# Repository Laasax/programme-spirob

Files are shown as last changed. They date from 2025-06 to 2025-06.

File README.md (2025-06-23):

> Open this page at [https://laasax.github.io/programme-spirob/](https://laasax.github.io/programme-spirob/)

# Spirob - TUS - Tentacule Ultra Sophistiqué
## 1.1. Descriptif du projet
Le projet est à l’initiative d’un professeur de technologie du collège Les Hautes Ourmes de Rennes.
Il s'agit de la conception et du développement d'un tentacule biomimétique, s'inspirant des propriétés d'un tentacule de poulpe ou d'une trompe d'éléphant. Cette approche repose sur le mimétisme, une stratégie qui consiste à s'inspirer du fonctionnement des êtres vivants pour concevoir une nouvelle solution de bras robotique.
Le tentacule Spirobs sera conçu de manière à reproduire des mouvements fluides et adaptatifs similaires à ceux observés dans la nature. Ce projet implique plusieurs disciplines techniques, notamment la modélisation 3D, l'électronique, la programmation embarquée et un contrôle à distance via Bluetooth.

## 1.2. Objectifs
L'objectif principal du projet est de fournir un outil pédagogique permettant aux collégiens de découvrir les principes fondamentaux de la programmation et de la robotique dans le cadre de la matière Technologie.
Impression 3D : Mettre en place l’impression du tentacule et trouver le filament correspondent (pour correspondre à l’élasticité du bras)
Développement d'une librairie logicielle : Fournir des méthodes simples par le biais d’une librairie pour l’utiliser sur l’interface Makecode de Microsoft, afin qu’elle soit facilement utilisée par les collégiens.
Intégration d’un moyen communicant sans fil : Utilisation du module Bluetooth intégré de la carte MicroBit.

## 1.3. Composition des membres du projet
Pour réaliser ce projet, la composition de ce groupe sera composée de :
* Binta Ba
* Mouhsine Ben Chakrina
* Hugo Colombel
* Alexandre Bloino

# 2. Pré-requis

Installer les librairies suivantes:
* Radio

# 3. Pins utilisés

Voici l'ensemble des pins utilisés par rapport à la carte électronique conçu pour ce projet.

* P0	: Controle Moteur 1
* P1	: Feedback Moteur 1
* P2	: Feedback Moteur 2
* P3	: Mesure intensité Moteur 1
* P8	: Controle Moteur 2
* P10	: Mesure intensité Moteur 2

# 4. Description du dépot Github

Ce dépot Github comporte principalement la partie programmation sur Makecode de la tentacule.

## 4.1 Dossier Ressources

Ce dossier possède tous les plans et schémas pour réaliser le Spirob.
* Electronique:
Le schéma électronique est fait avec le logiciel Proteus, un gerber est fournie pour refaire des cartes.
* CAO 3D:
La réalisation 3D est faite avec le logiciel Solidworks, tous les fichiers STL sont fournies pour pouvoir les imprimer (boitier, tentacule...)

## 4.2 Dossier Images

Ce dossier permet de répertorier les captures d'écran / photo liés au projet, permettant de le contextualiser.

# 5. Fonctionnement du programme

## 5.1 Importer le programme 

### 5.1.1 Carte émettrice
Pour la carte émettrice, la librairie Radio doit être importée.
Dans ce programme, il faut prendre la fonction Radio Set Group, la mettre dans la boucle Setup, il faut ensuite, dans la boucle infini, envoyé l'orientation "roll" toutes les 50ms sur la communication radio.



### 5.1.2 Carte réceptrice
Pour la carte réceptrice, il faut importer le dépot Git depuis le bouton extension, puis coller le lien Git.

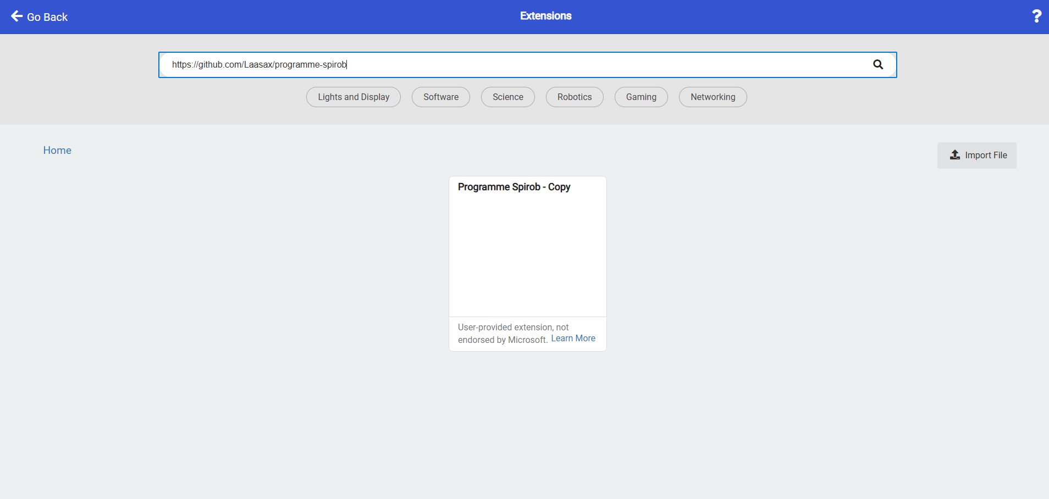
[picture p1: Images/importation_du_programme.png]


## 5.2 Fonctionnement
Afin de faire fonctionner le Spirob, il faut alimenter les 2 cartes MicroBit et alimenter la carte des servomoteurs.
Lorsque tout est alimenté, il suffit d'orienter de gauche à droite pour apprécier les mouvements de la tentacule.

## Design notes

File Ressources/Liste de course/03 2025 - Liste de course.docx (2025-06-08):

Gotronic :

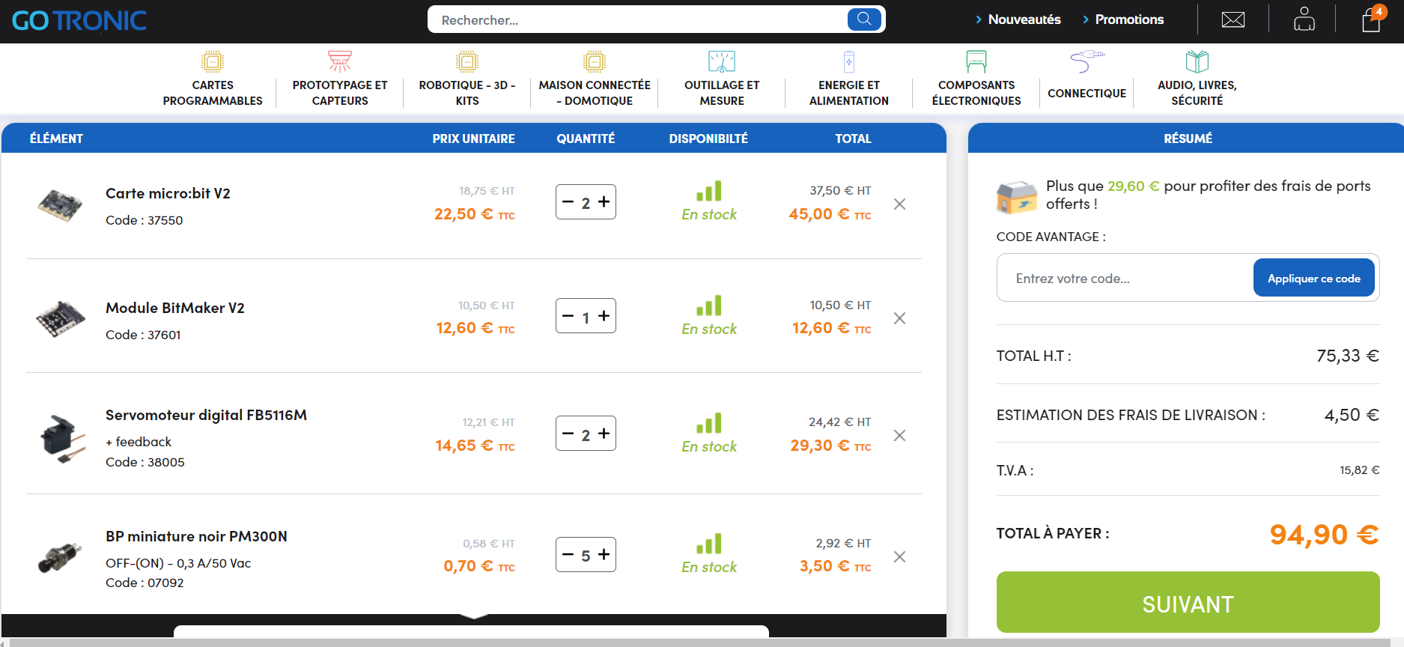
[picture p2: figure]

Mouser :

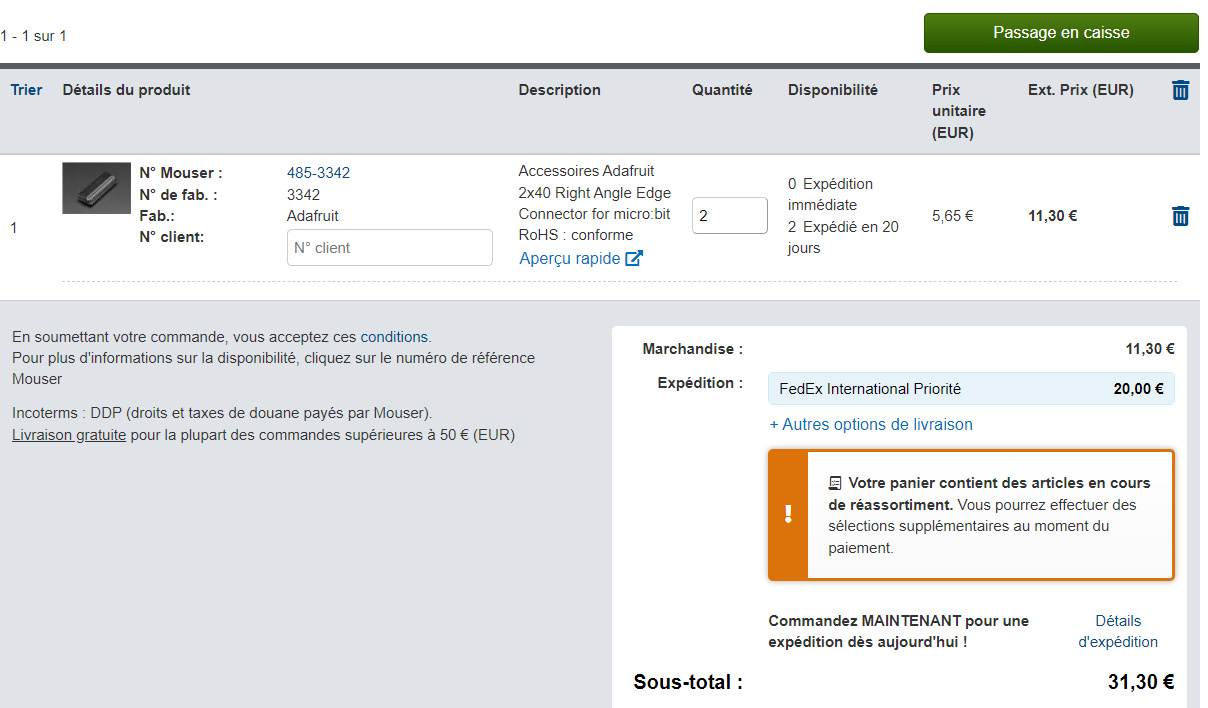
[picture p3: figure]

Atlantic Composant :

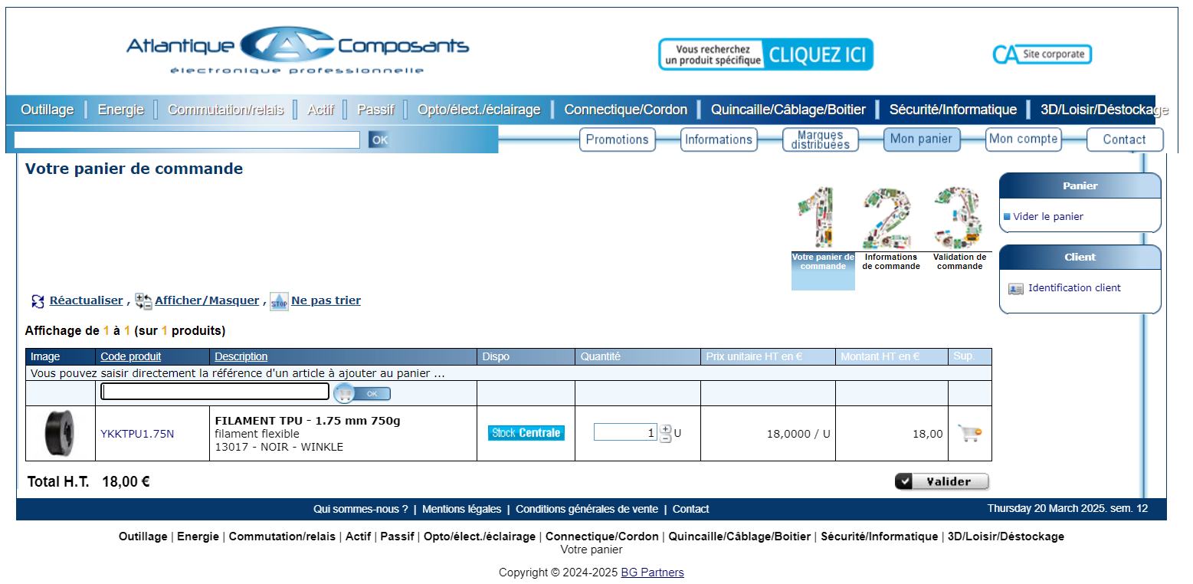
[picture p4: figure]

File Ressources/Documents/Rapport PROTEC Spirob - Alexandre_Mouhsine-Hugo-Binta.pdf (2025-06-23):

# Spirob – TUS – Tentacule Ultra Sophistiqué

BLOINO Alexandre
ESIR,
Université de Rennes
France
alexandre.bloino@etudia
nt.univ-rennes.fr

BA Mamadou Binta
ESIR,
Université de Rennes
France
mamadoubinta.ba@etudiant.univ-rennes.fr

COLOMBEL Hugo
ESIR,
Université de Rennes
France
hugo.colombel@etudiant
.univ-rennes1.fr

CHAKRINA Mouhsine
Ben
ESIR,
Université de Rennes
France
mouhsineben.chakrina@etudiant.u
niv-rennes.fr

Abstract

Projet de bras robotique biomimétique conçu pour l’enseignement de la technologie au collège. TUS s’inspire du mouvement des tentacules pour créer une interface programmable, contrôlée via une carte

MicroBit en Bluetooth. Ce rapport décrit la conception mécanique, les choix techniques, et l’implémentation logicielle avec l’objectif de créer un outil pédagogique accessible aux collégiens.

Index Terms – Biomimétisme ; Robotique pédagogique ; Impression 3D ; MicroBit ; Bluetooth ; MakeCode

I. INTRODUCTION

Le projet d’un bras robotique, reprenant la forme d’un tentacule, est un projet qui s’inscrit dans la matière PROTEC de notre formation SNR à l’ESIR. Ce projet est à l’initiative d’un professeur de technologie de collège Les Hautes Ourmes à Rennes.

Comment concevoir un système permettant de contrôler un tentacule, programmable et accessible à des collégiens ?

L’objectif de ce projet est de développer un système permettant de contrôler le tentacule à l’aide de servomoteur, avec une ou deux cartes MicroBit, contrôlable via MakeCode.

Ce document est organisé de la manière suivante : Introduction, Etat de l’art, Desciption du projet, Résultats expérimentaux et Conclusion.

II. ETAT DE L’ART

a. Tentacules robotique open source

La robotique biomimétique vise à reproduire le comportement ou la structure des êtres vivants pour créer des systèmes artificiels. Un domaine en particulier, la robotique molle (soft robotics), s’inspire des propriétés mécaniques d'organismes comme les poulpes, les vers ou les éléphants pour produire des robots souples, capables de se faufiler, saisir des objets fragiles ou se mouvoir dans des environnements complexes.

Dans le domaine amateur et pédagogique, plusieurs modèles de tentacules ont été partagés en open source par la communauté des makers. Ils sont généralement imprimés en 3D

Dans ce cadre, les tentacules robotiques représentent une catégorie particulière, alliant souplesse, enroulement et précision. Ils sont souvent utilisés pour démontrer des capacités d’interaction avancée avec l’environnement, bien au-delà des robots articulés classiques.

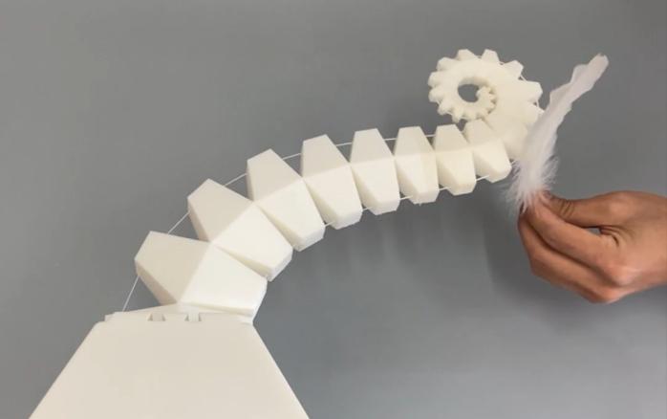
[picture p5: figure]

Figure 1 : Capture d'écran de la vidéo "Video S4. Contact detection." [1]

Ces bras sont articulés par des câble reliés à des moteurs, et le tentacule est imprimé avec un matériau flexible TPU de type 95A.

Pour notre projet, nous avons identifié un modèle de tentacule open source disponible en ligne, conçu pour être imprimé en 3D et manipulé par un seul moteur. Ce modèle, que nous avons trouvé via GitHub, constitue la seule partie réutilisée dans notre projet. Il nous a permis de bénéficier d’une structure mécanique souple et fonctionnelle dès le début du développement. [1]

b. Absence de solutions intégrées pédagogiques

Afin que des collégiens puissent l’utiliser de manière adéquate,

Dans le cadre éducatif, il existe de nombreux kits robotiques conçus pour l’enseignement (Galaxia, Lego Mindstorms, Thymio, mBot, Micro:bit), qui utilisent des structures de programmation en bloque. Ces solutions sont adaptées pour apprendre les bases de la logique, du codage et de l’électronique, mais elles ne proposent pas de mécanismes souples ni de composants biomimétiques.

De plus, les solutions de robotique souple existantes sont rarement compatibles avec des interfaces éducatives comme MakeCode, qui vise l’apprentissage de la programmation par blocs.

III. PROJET ET PROPOSITON

a. Vue d’ensemble

Le projet TUS (Tentacule Ultra Sophistiqué) est un bras robotique souple inspiré du biomimétisme. Il est contrôlé à distance via Bluetooth à l’aide d’une carte MicroBit. Le tentacule est imprimé en 3D avec du filament TPU, ce qui lui donne de la souplesse. Un servo-moteur actionne le bras, commandé par la MicroBit. L’ensemble permet d’obtenir des mouvements fluides, similaires à ceux observés dans la nature.

b. Méthodologie

Nous avons commencé par chercher la méthode d’impression du tentacule sur l’article de ScienceDirect [1], nous avons testé deux types de filament TPU, l’un en 98A, l’autre en 95A. A titre d’information, comme le montre le graphique cidessous, plus la valeur qui précède le A est élevé, plus elle est rigide, et à l’inverse, plus elle est basse, plus elle est souple. La structure a ensuite imprimé en TPU pour valider sa flexibilité.

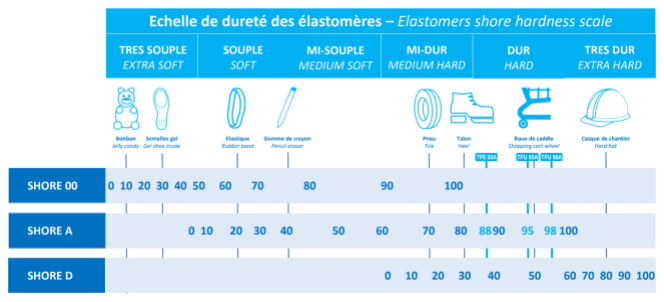
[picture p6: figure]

Figure 2 : Comparaison sur une échelle, l'élasticité de différents matériaux élastiques [2] [3]

Côté électronique, nous avons câblé la MicroBit au servo, puis programmé les premiers tests de mouvement. Enfin, nous avons développé une librairie personnalisée MakeCode pour permettre une programmation simple en blocs, adaptée aux élèves de collège.

c. Architecture logicielle et matériel

Le système fonctionne ainsi : la MicroBit reçoit des commandes Bluetooth depuis une autre carte MicroBit. Elle contrôle ensuite le servo-moteur, qui agit mécaniquement sur le tentacule. L’électronique est simple : une carte MicroBit avec une alimentation externe via une prise USB, un servomoteur avec une alimentation externe de 5V.

La partie logicielle repose sur MakeCode, dans lequel nous avons intégré une librairie dédiée avec des blocs faciles à utiliser, en utilisant les fonctions d’envoie et de réception en radio, et l’utilisation des servomoteurs.

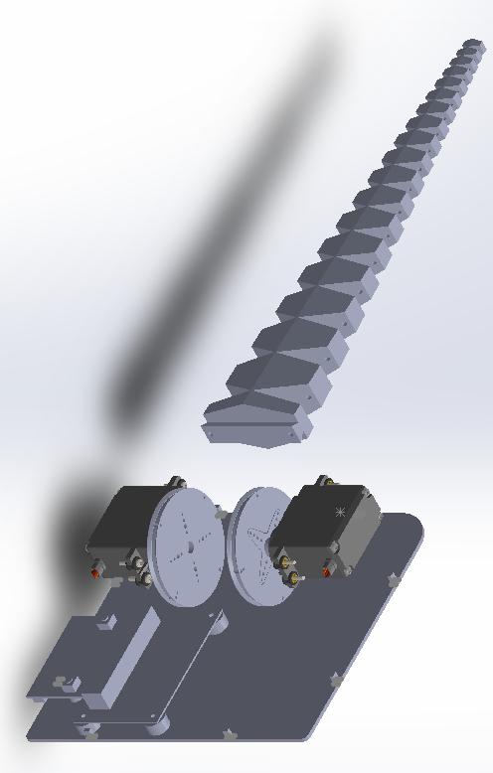
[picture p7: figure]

Figure 3 : Représentation 3D du boitier et de ses composants

IV. RESULTATS D’EXPERIMENTATION

a. Résultats mécaniques

Nous avions fait imprimer 2 tentacules en TPU, l’un en 98A, l’autre en 95A, en les testant, il s’est avérer que le tentacule imprimé en TPU 95A possédé de meilleurs propriété d’élasticité que celui en 98A, celui-ci est moins rigide, ce qui demande moins de force pour tirer la tentaculé. Plus l’on a besoins de force pour replier la tentacule, plus nous avons besoin de servomoteur conséquent, ce qui augmente le coût du projet et la taille du produit.

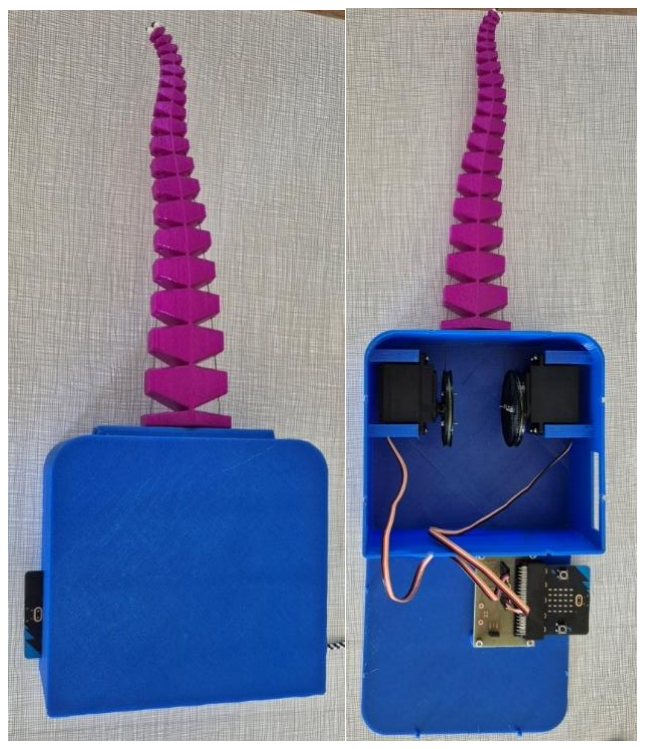
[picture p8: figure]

Figure 4 : Résultat mécanique du boitier et de l'électronique b. Résultats électroniques

Le système, composé d’une carte MicroBit connectée à un servomoteur, a permis d’obtenir un contrôle fluide du tentacule. Les commandes Bluetooth envoyées depuis une seconde MicroBit ont été reçues avec une latence très faible, assurant une bonne réactivité.

Le bras effectue des mouvements d’enroulement sur un angle d’environ 120°, de manière répétable et stable.

c. Résultats logiciels

Le projet peut être repris depuis GitHub assez facilement, lorsqu’il est repris, cela envoie le programme entier dans l’interface MakeCode, ce qui rend facilement modifiable le programme.

d. Limitations observées
- Malgré sa souplesse, le système reste limité à un seul degré de liberté, ce qui restreint les possibilités de mouvement.
- L’absence de capteurs embarqués empêche tout retour d’information sur la position du tentacule.
- Par ailleurs, l’alimentation via la MicroBit seule est insuffisante ; une alimentation externe est indispensable pour le bon fonctionnement du servomoteur.
e. Améliorations envisagées
- Ajout de roues motorisé sous le boitier, permettant de déplacer le tentacule facilement.
- Changement des moteurs pour avoir une meilleure course
V. CONCLUSION

Le projet TUS a permis de concevoir un tentacule robotique souple, fonctionnel et accessible, destiné à l’apprentissage de la programmation et de l’électronique au collège. Grâce à l’utilisation de matériaux flexibles comme le TPU 95A, à une architecture simple autour de la MicroBit, et à l’intégration d’une interface de programmation par blocs via MakeCode, nous avons pu proposer une solution pédagogique concrète et facilement réutilisable.

Les tests ont démontré la faisabilité du concept et mis en lumière plusieurs axes d’amélioration, comme l’ajout de roues motorisées ou l’intégration de moteurs plus performants. Le projet constitue ainsi une base solide pour le développement de systèmes biomimétiques éducatifs simples, ouverts et attractifs pour les jeunes apprenants.

REFERENCES

[1] Z. Wang, N. M. Freris et X. Wei, «SpiRobs: Logarithmic spiral-shaped robots for versatile grasping across scales,» [En ligne]. Available: https://www.sciencedirect.com/science/article/pii/S2666998624006033.
[2] Francofil, [En ligne]. Available: https://francofil.fr/product/tpu-95a-noir/.
[3] Francofil, «Guide matériaux - TPU,» [En ligne]. Available: https://francofil.fr/guide-des-materiaux/tpu/.
[4] A. Bloino, «programme-spirob,» 2025. [En ligne]. Available: https://github.com/Laasax/programme-spirob.

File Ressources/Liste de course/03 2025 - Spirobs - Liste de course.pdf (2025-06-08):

Gotronic :

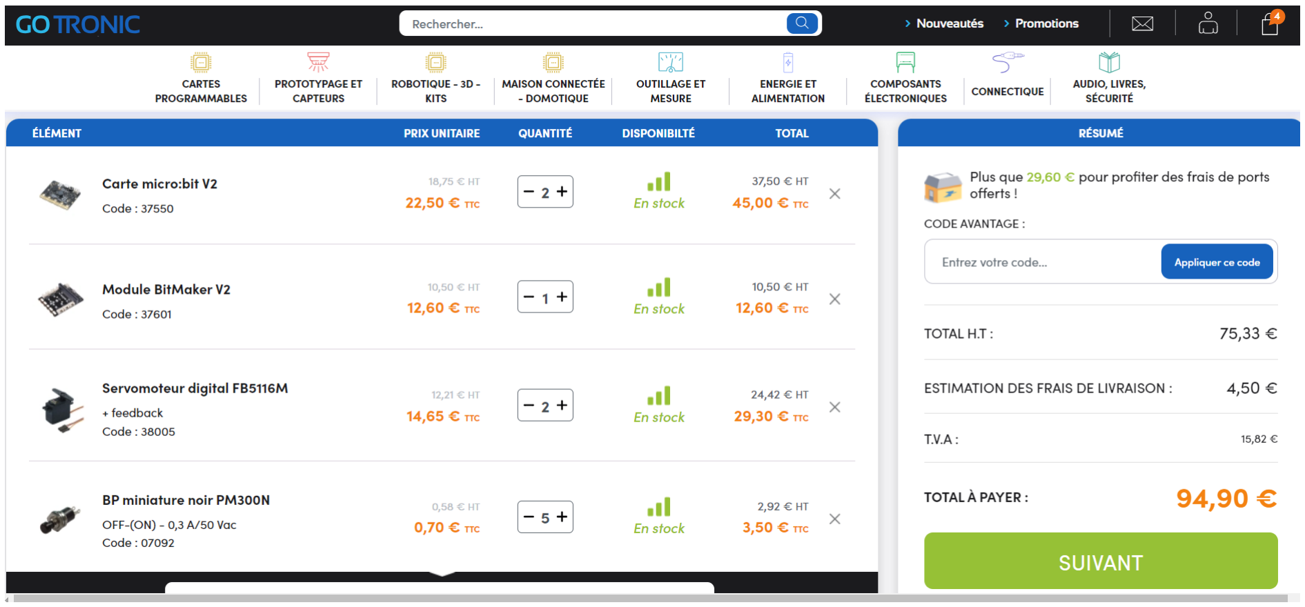
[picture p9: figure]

Mouser :

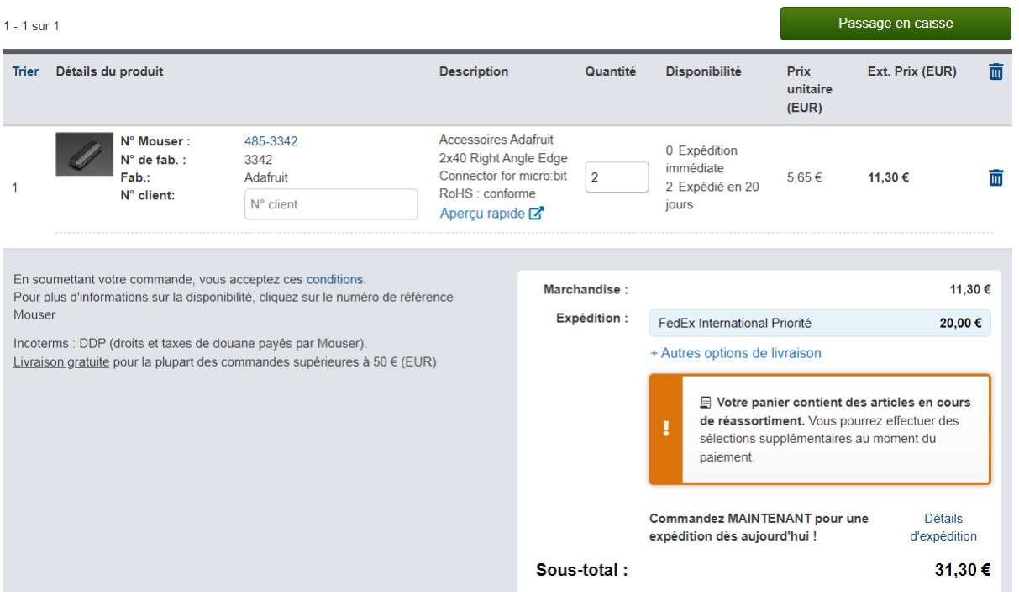
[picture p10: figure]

Atlantic Composant :

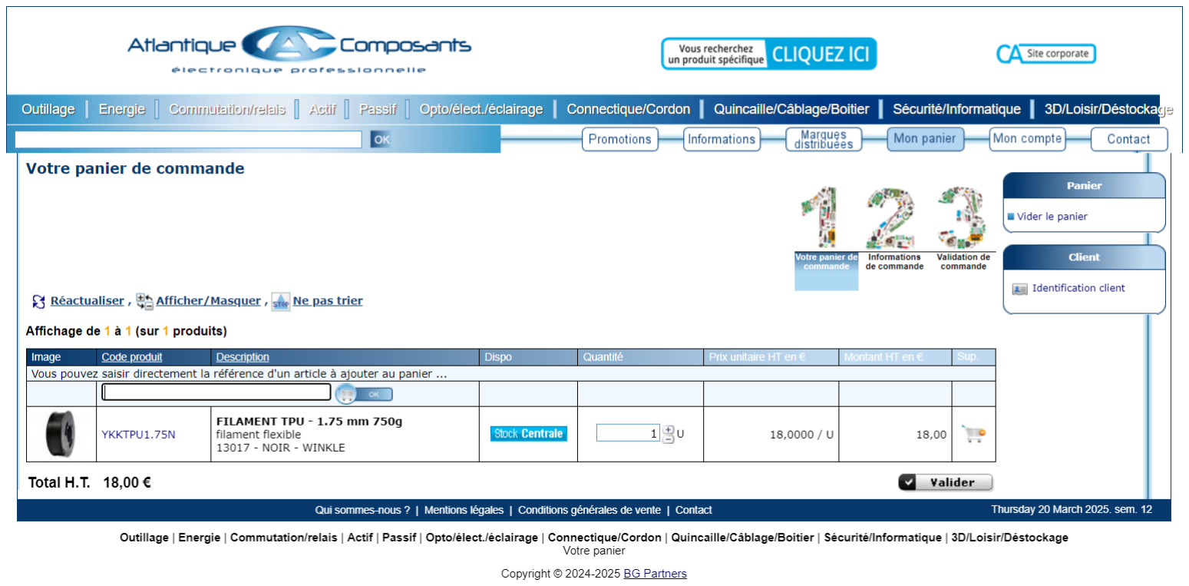
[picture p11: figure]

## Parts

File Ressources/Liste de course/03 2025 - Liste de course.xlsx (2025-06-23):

Désignation du produit | Réf fournisseur | Réf constructeur | Fournisseur | Lien | Prix € HT Unitaire | Prix € TTC Unitaire | QTE | Total € HT | Total € TTC
Carte Micro:bit | 37550 |  | GoTronic | https://www.gotronic.fr/art-carte-micro-bit-v2-34688.htm | 18.75 € | 22.50 € | 2 | 37.50 € | 45.00 € | Total € HT | Total € TTC
Carte de développement Grove pour Microbit | 37601 |  | GoTronic | https://www.gotronic.fr/art-module-bitmaker-v2-34970.htm | 10.50 € | 12.60 € | 1 | 10.50 € | 12.60 € | 110.27 € | 128.95 €
Connecteur traversant microbit 90° | 485-3342 | 3342 | Mouser | https://www.mouser.fr/ProductDetail/Adafruit/3342?qs=IP4CA2YhK0CGpdvM3aFp3w%3D%3D | 5.65 € | 5.65 € | 3 | 16.95 € | 16.95 €
Filament TPU flexible - 95A | YKKTPU1.75N |  | Atlantic Composant | https://www.atlantique-composants.fr/ProductCard/YKKTPU1.75N/filament-tpu-1-75-mm-750g | 18.00 € | 21.60 € | 1 | 18.00 € | 21.60 €
Servomoteur | 38005 |  | GoTronic | https://www.gotronic.fr/art-servomoteur-digital-fb5116m-36024.htm | 12.21 € | 14.65 € | 2 | 24.42 € | 29.30 €
Bouton poussoir | 7092 |  | GoTronic | https://www.gotronic.fr/art-bp-miniature-noir-pm300n-4244.htm | 0.58 € | 0.70 € | 5 | 2.90 € | 3.50 €
UHMWPE ficelle 0.5mm Fil de pêche |  |  |  |  |  |  |  | 0.00 € | 0.00 €

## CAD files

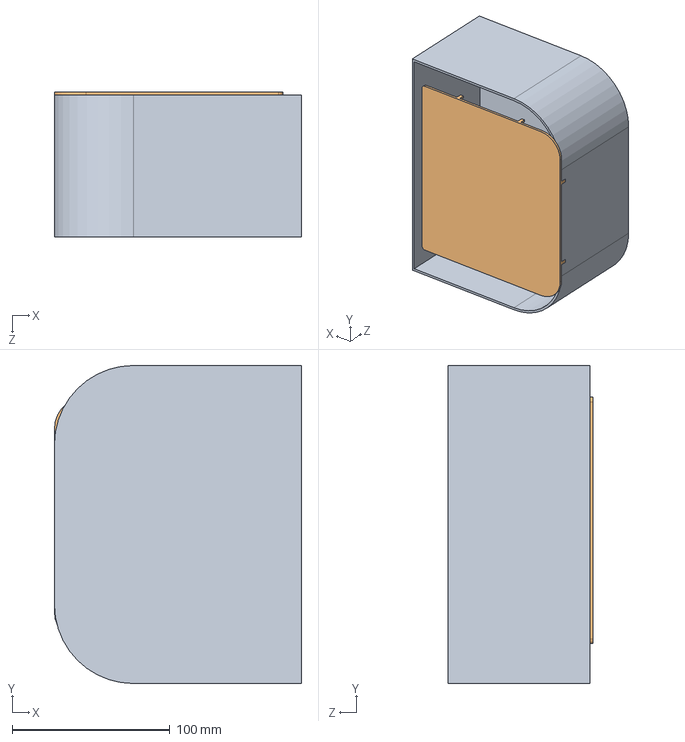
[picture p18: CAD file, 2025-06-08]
Ressources/Fichiers 3D/boitier/boitier.SLDASM
156.6 x 201.5 x 92.0 mm
dessous
coque

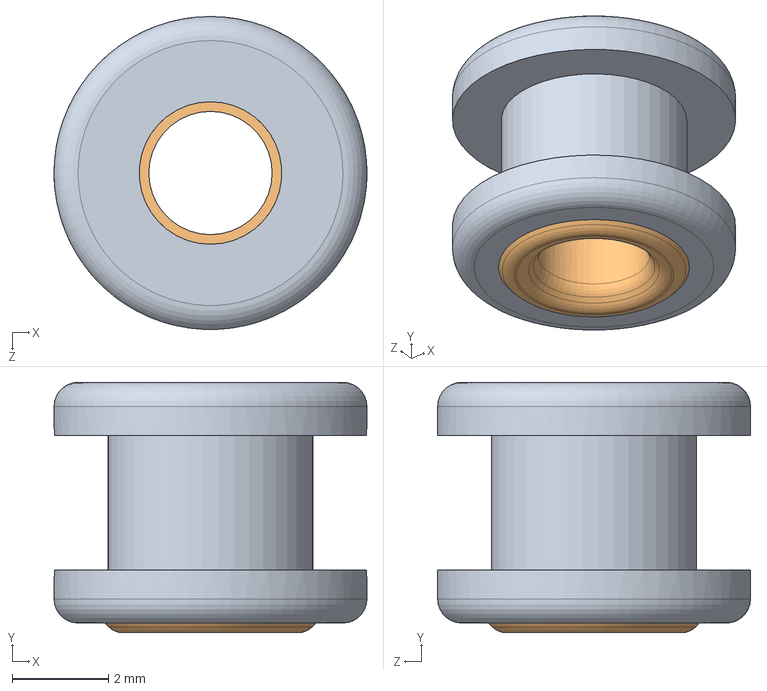
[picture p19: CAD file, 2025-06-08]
Ressources/Fichiers 3D/servomoteur/SolidWorks 2014/FS5109M_Ensemble silent-bloc.SLDASM
6.50 x 5.20 x 6.50 mm
FS5109M_silent-bloc
FS5109M_silent-bloc_douille

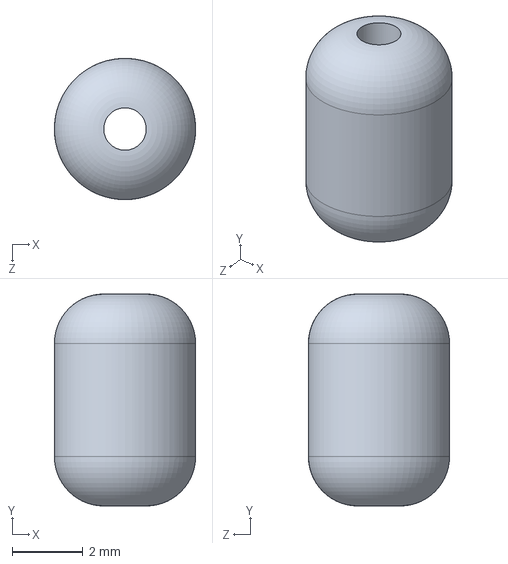
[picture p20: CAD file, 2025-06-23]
Ressources/Fichiers 3D/embout fils.SLDPRT
4.00 x 6.00 x 4.00 mm

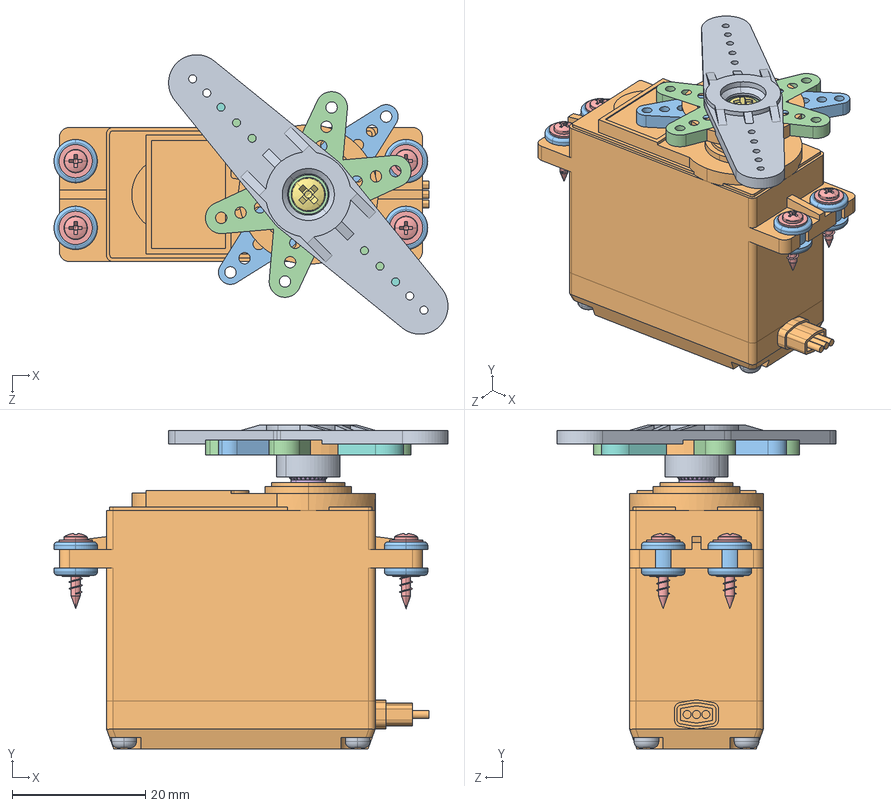
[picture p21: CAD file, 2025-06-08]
Ressources/Fichiers 3D/servomoteur/FS5109M_Ensemble servo.STEP
59.0 x 48.5 x 41.9 mm
FS5109M_corps
FS5109M_silent-bloc x 4
FS5109M_silent-bloc_douille x 4
FS5109M_vis servo 2 x 10_ISO 7045 - M2 x 10 - Z --- 10N x 4
FS5109M_arbre
FS5109M_vis arbre M3 x 6_vis arbre M3 x 6
FS5109M_palo 2S
FS5109M_palo 2B
FS5109M_palo C
FS5109M_palo 4
FS5109M_palo 6

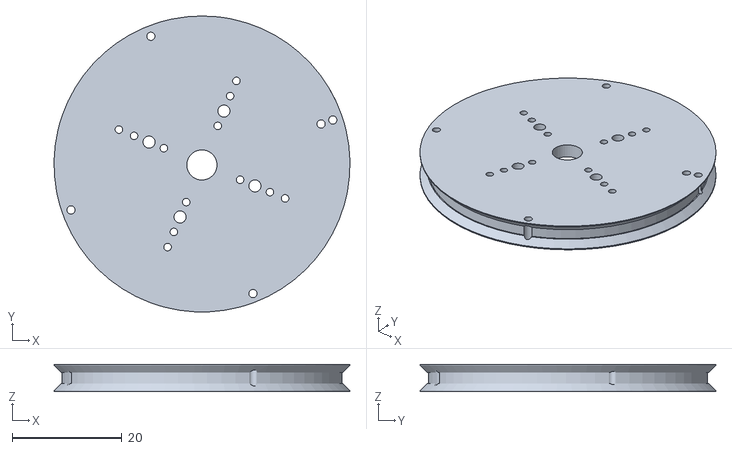
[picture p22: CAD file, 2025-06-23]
Ressources/Fichiers 3D/STL/poulie ronde.STL
54.0 x 54.0 x 5.00

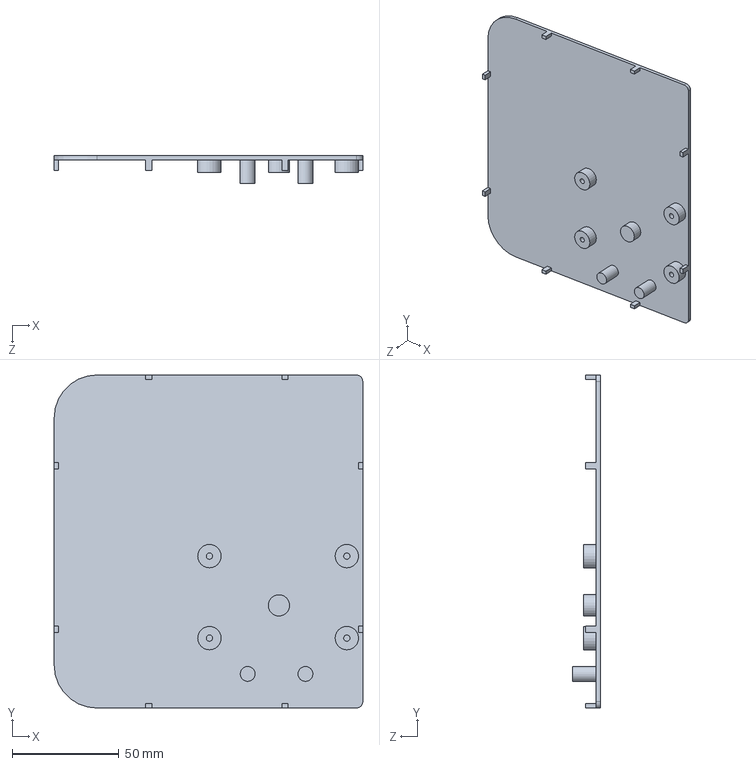
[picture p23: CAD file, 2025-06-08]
Ressources/Fichiers 3D/boitier/dessous.SLDPRT
144.9 x 156.3 x 13.0 mm

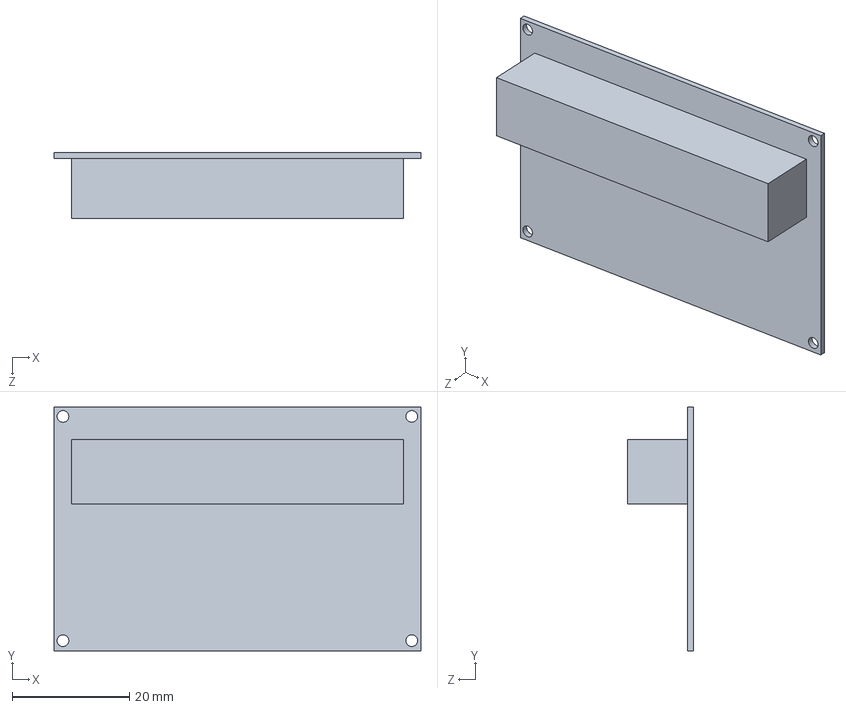
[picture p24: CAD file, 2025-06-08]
Ressources/Fichiers 3D/micro bit/carte alim.SLDPRT
62.5 x 41.5 x 11.2 mm

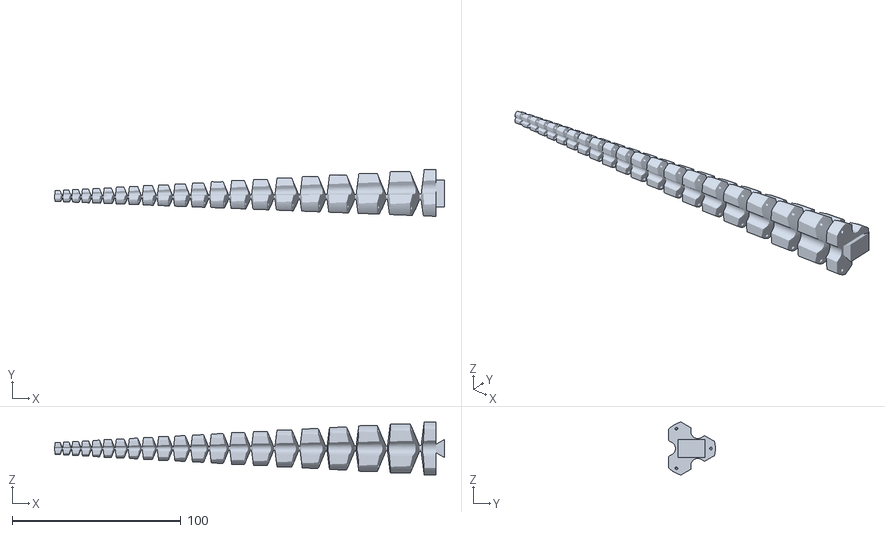
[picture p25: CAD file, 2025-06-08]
Ressources/Fichiers 3D/STL/3-cable SpiRob.STL
231.3 x 27.8 x 31.4

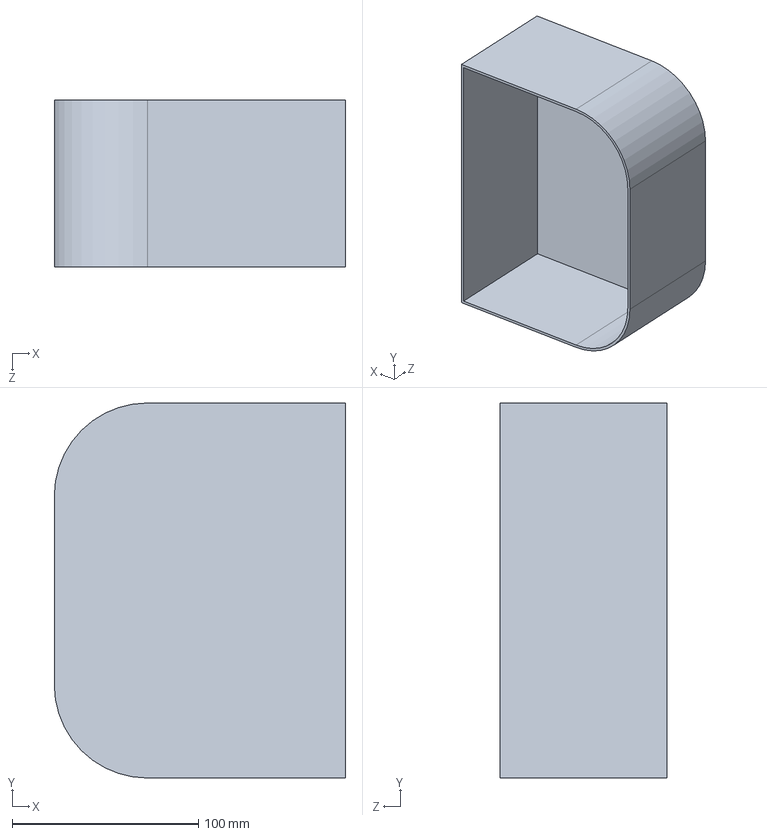
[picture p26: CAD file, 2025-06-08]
Ressources/Fichiers 3D/boitier/coque.SLDPRT
156.6 x 201.5 x 90.0 mm

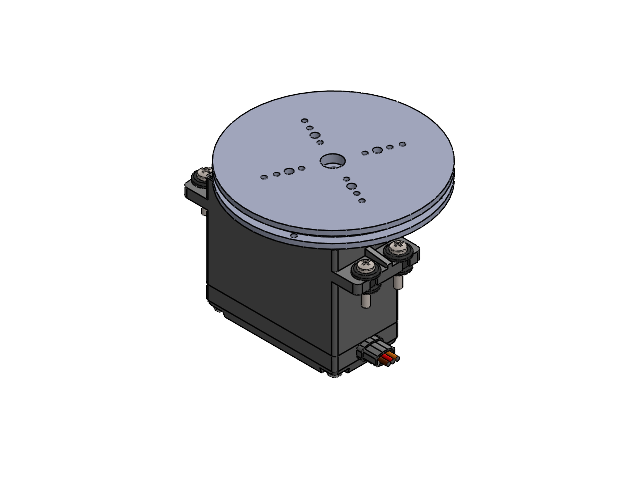
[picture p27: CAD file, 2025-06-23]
Ressources/Fichiers 3D/Assemblage/moteur+poulie.SLDASM
FS5109M_corps
FS5109M_silent-bloc x 4
FS5109M_silent-bloc_douille x 4
pan head cross recess screw_iso x 4
FS5109M_arbre
poulie servo
poulie ronde

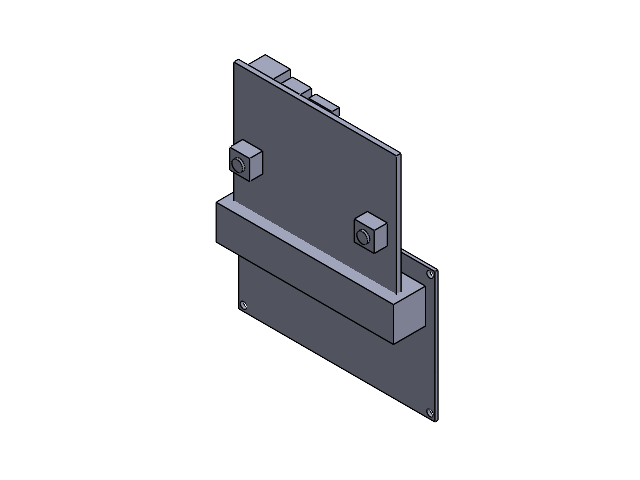
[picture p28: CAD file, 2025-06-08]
Ressources/Fichiers 3D/micro bit/assemblage carte alim + microbit.SLDASM
carte alim
carte microbit

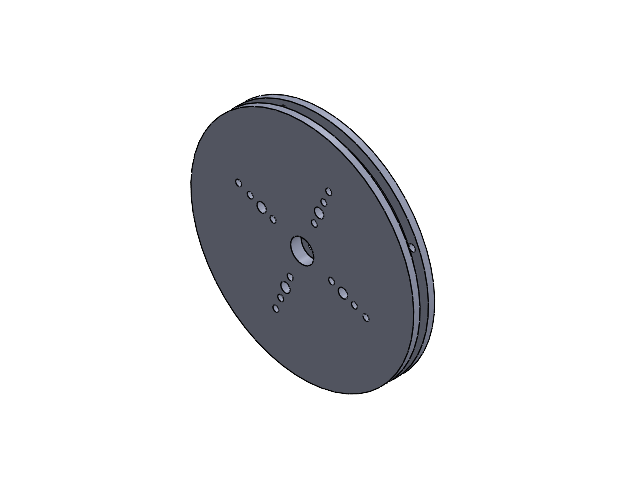
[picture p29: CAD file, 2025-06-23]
Ressources/Fichiers 3D/poulie/poulie fil.SLDASM
poulie servo
poulie ronde

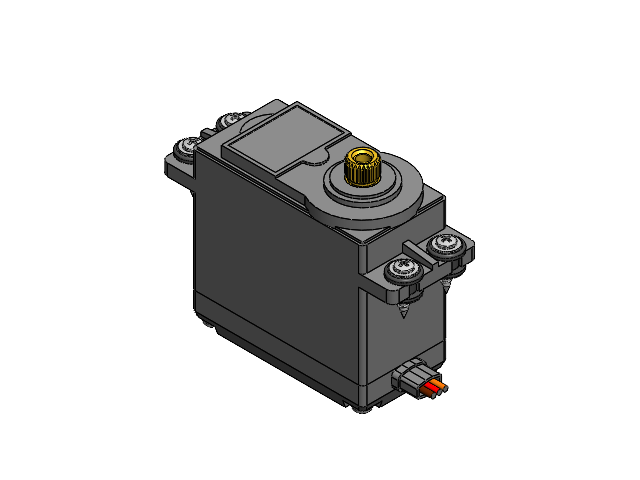
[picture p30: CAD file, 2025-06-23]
Ressources/Fichiers 3D/servomoteur/SolidWorks 2014/FS5109M_Ensemble servo.SLDASM
FS5109M_corps
FS5109M_silent-bloc x 4
FS5109M_silent-bloc_douille x 4
pan head cross recess screw_iso x 4
FS5109M_arbre

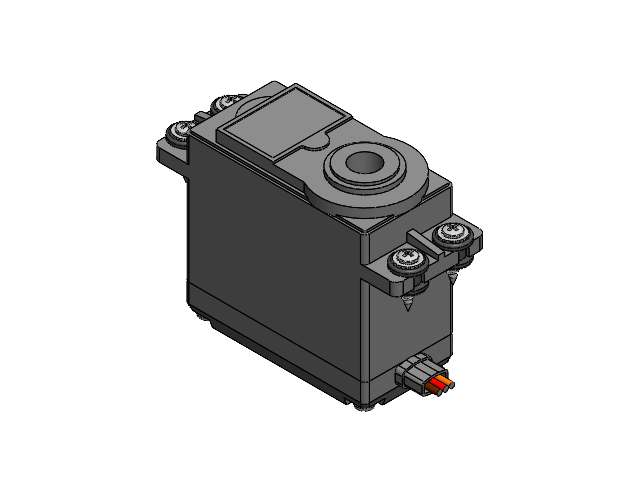
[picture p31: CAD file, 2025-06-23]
Ressources/Fichiers 3D/servomoteur/SolidWorks 2014/FS5109M_Ensemble corps.SLDASM
FS5109M_corps
FS5109M_silent-bloc x 4
FS5109M_silent-bloc_douille x 4
pan head cross recess screw_iso x 4

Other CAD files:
Ressources/Fichiers 3D/micro bit/assemblage carte micro bit et carte moteur.SLDASM
Ressources/Fichiers 3D/servomoteur/SolidWorks 2014/FS5109M_Ensemble arbre.SLDASM
Ressources/Fichiers 3D/boitier.SLDPRT
Ressources/Fichiers 3D/poulie/poulie ronde.SLDPRT
Ressources/Electronique/Librairie/114020164/3D/114020164.stp
Ressources/Electronique/Librairie/114020164/Allegro/114020164.psm
Ressources/Electronique/Librairie/114020164/DEHDL/114020164/chips/chips.prt
Ressources/Electronique/Librairie/3342/Allegro/3342.psm
Ressources/Electronique/Librairie/3342/DEHDL/3342/chips/chips.prt
Ressources/Fichiers 3D/STL/2-cable SpiRob.STL
Ressources/Fichiers 3D/STL/coque.STL
Ressources/Fichiers 3D/STL/dessous.STL
Ressources/Fichiers 3D/STL/embout fils.STL
Ressources/Fichiers 3D/micro bit/carte microbit.SLDPRT
Ressources/Fichiers 3D/micro bit/carte moteur micro bit.SLDPRT
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

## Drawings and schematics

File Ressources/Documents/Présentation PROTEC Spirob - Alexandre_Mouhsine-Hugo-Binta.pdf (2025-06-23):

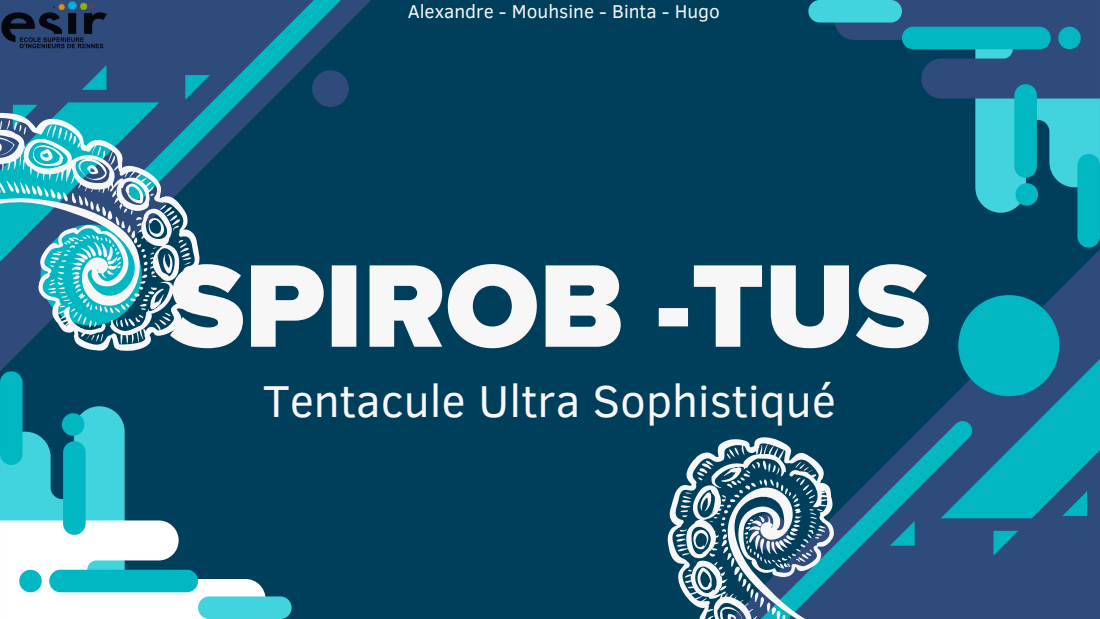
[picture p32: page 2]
SPIROB -TUS

Alexandre - Mouhsine - Binta - Hugo

Tentacule Ultra Sophistiqué

## Contexte du projet

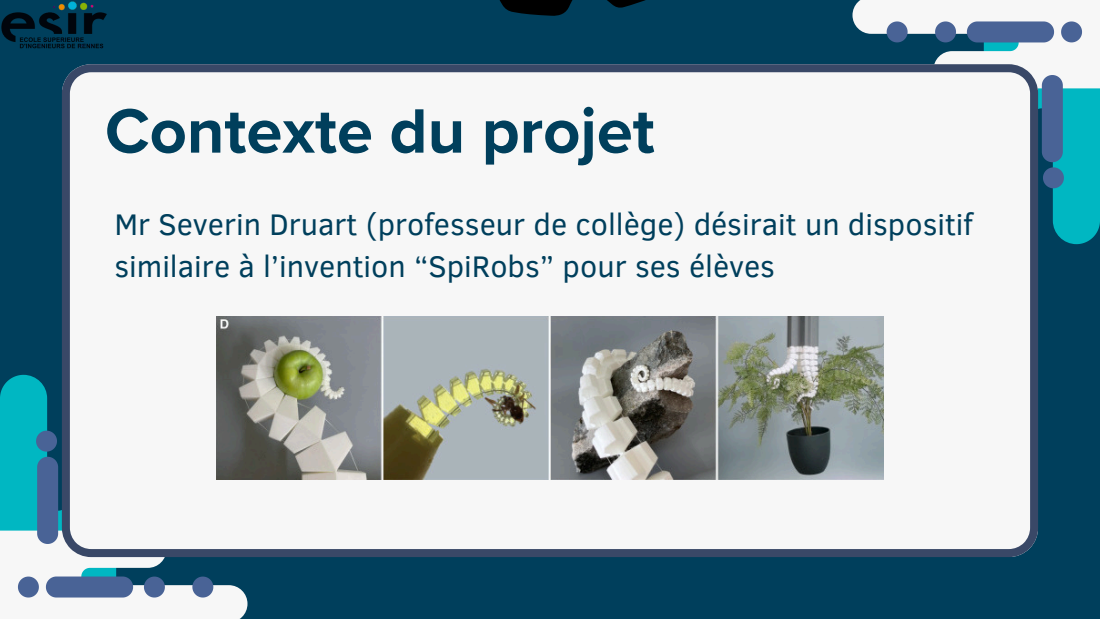
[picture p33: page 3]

Mr Severin Druart (professeur de collège) désirait un dispositif
similaire à l’invention “SpiRobs” pour ses élèves

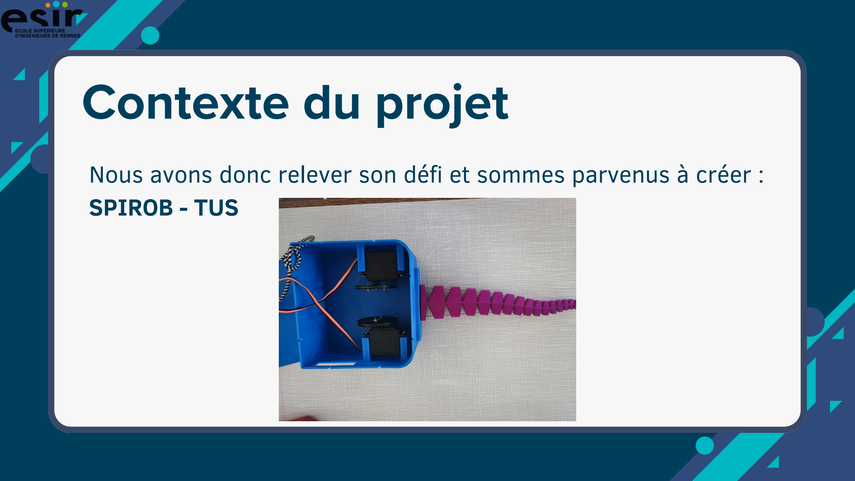
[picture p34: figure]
SPIROB - TUS; Contexte du projet

### Nous avons donc relever son défi et sommes parvenus à créer :

## Premières réflexions

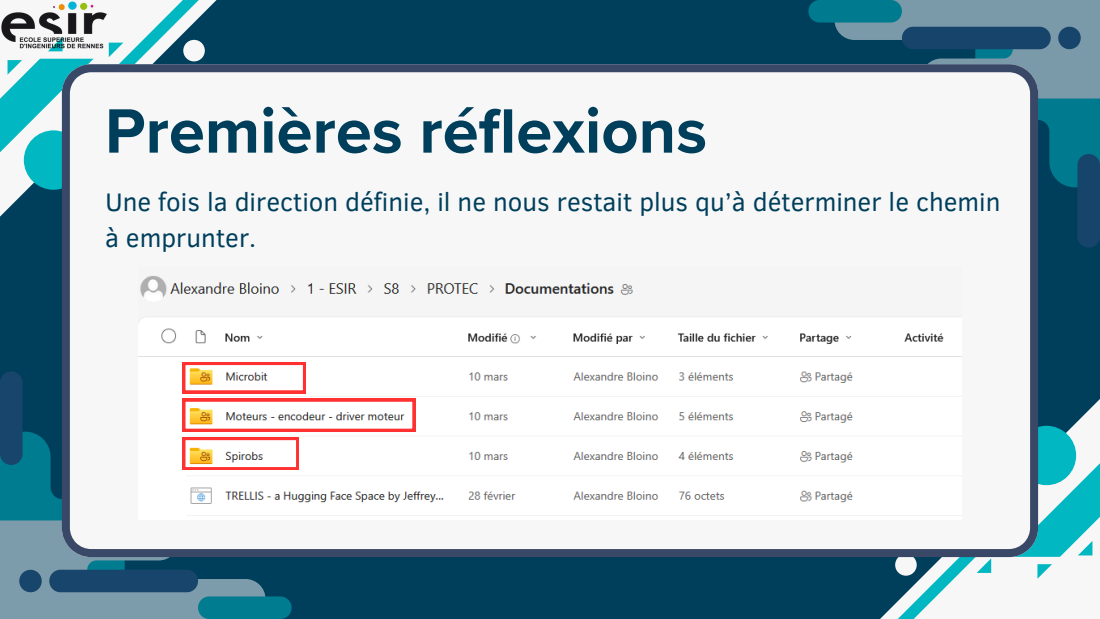
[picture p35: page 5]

Une fois la direction définie, il ne nous restait plus qu’à déterminer le chemin
à emprunter.

## Liste de courses

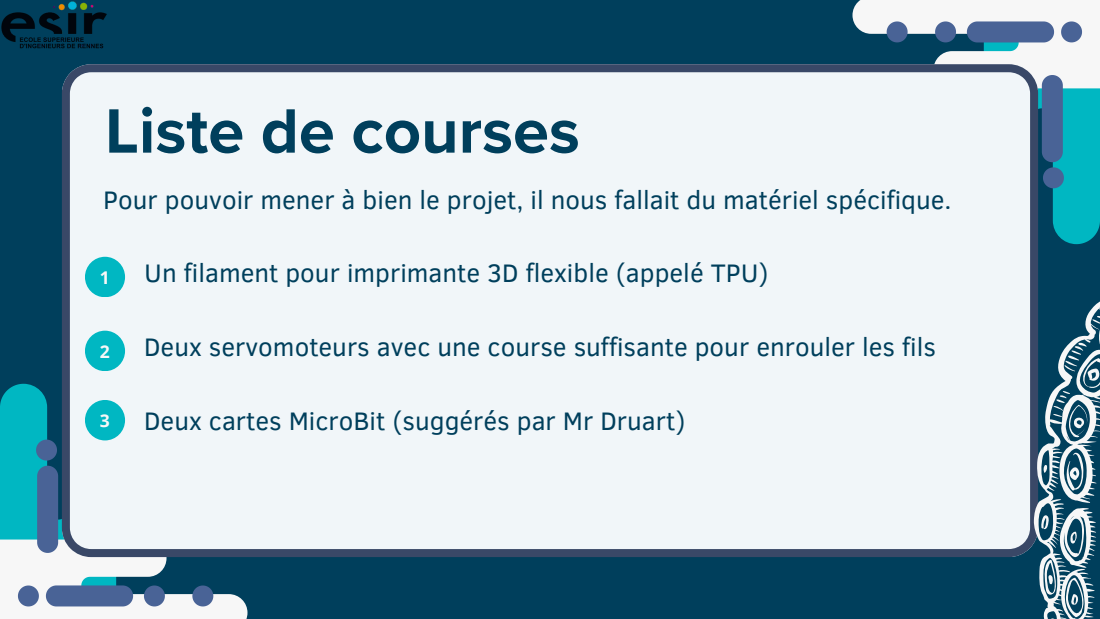
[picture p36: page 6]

Pour pouvoir mener à bien le projet, il nous fallait du matériel spécifique.

1 Un filament pour imprimante 3D flexible (appelé TPU)

2 Deux servomoteurs avec une course suffisante pour enrouler les fils

3 Deux cartes MicroBit (suggérés par Mr Druart)

## Premiers essais

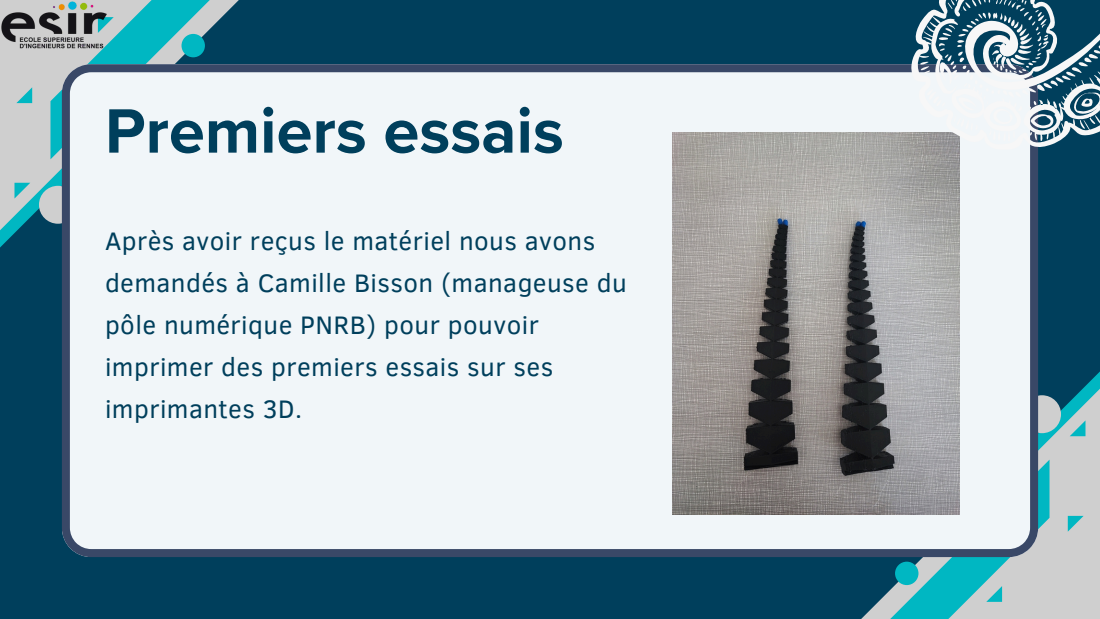
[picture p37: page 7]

Après avoir reçus le matériel nous avons
demandés à Camille Bisson (manageuse du
pôle numérique PNRB) pour pouvoir
imprimer des premiers essais sur ses
imprimantes 3D.

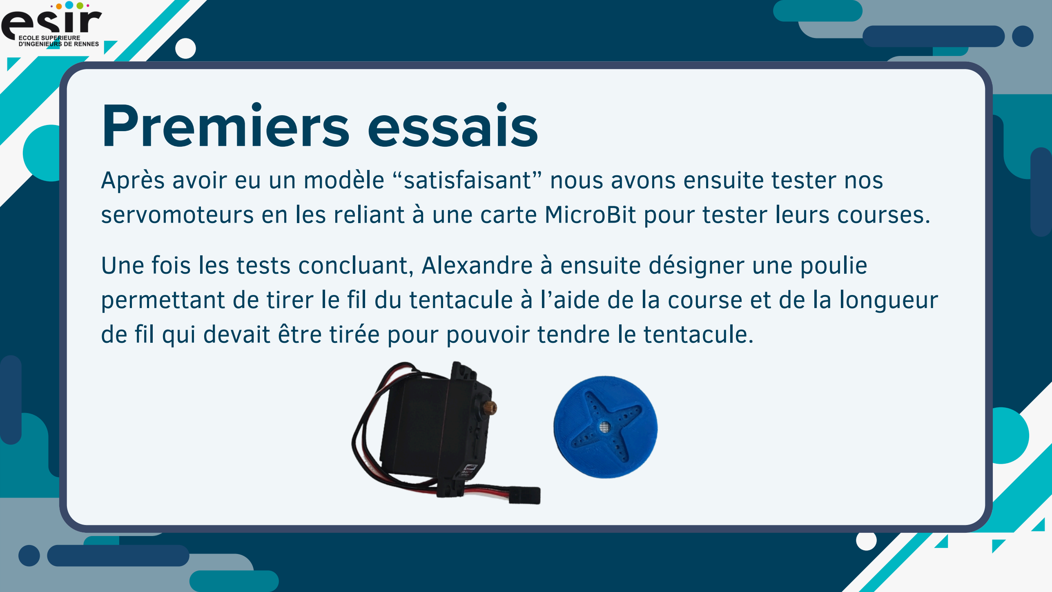
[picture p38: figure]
Premiers essais

Après avoir eu un modèle “satisfaisant” nous avons ensuite tester nos servomoteurs en les reliant à une carte MicroBit pour tester leurs courses. Une fois les tests concluant, Alexandre à ensuite désigner une poulie permettant de tirer le fil du tentacule à l’aide de la course et de la longueur de fil qui devait être tirée pour pouvoir tendre le tentacule.

## Premiers essais

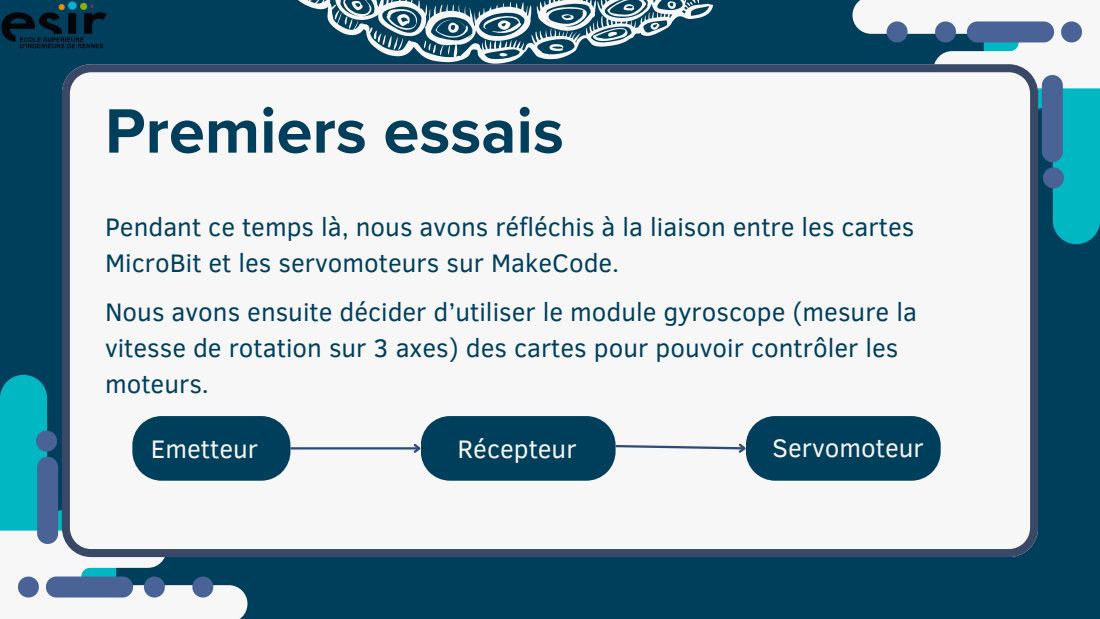
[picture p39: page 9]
Emetteur; Récepteur; Servomoteur

Pendant ce temps là, nous avons réfléchis à la liaison entre les cartes
MicroBit et les servomoteurs sur MakeCode.
Nous avons ensuite décider d’utiliser le module gyroscope (mesure la
vitesse de rotation sur 3 axes) des cartes pour pouvoir contrôler les
moteurs.

## Carte électronique

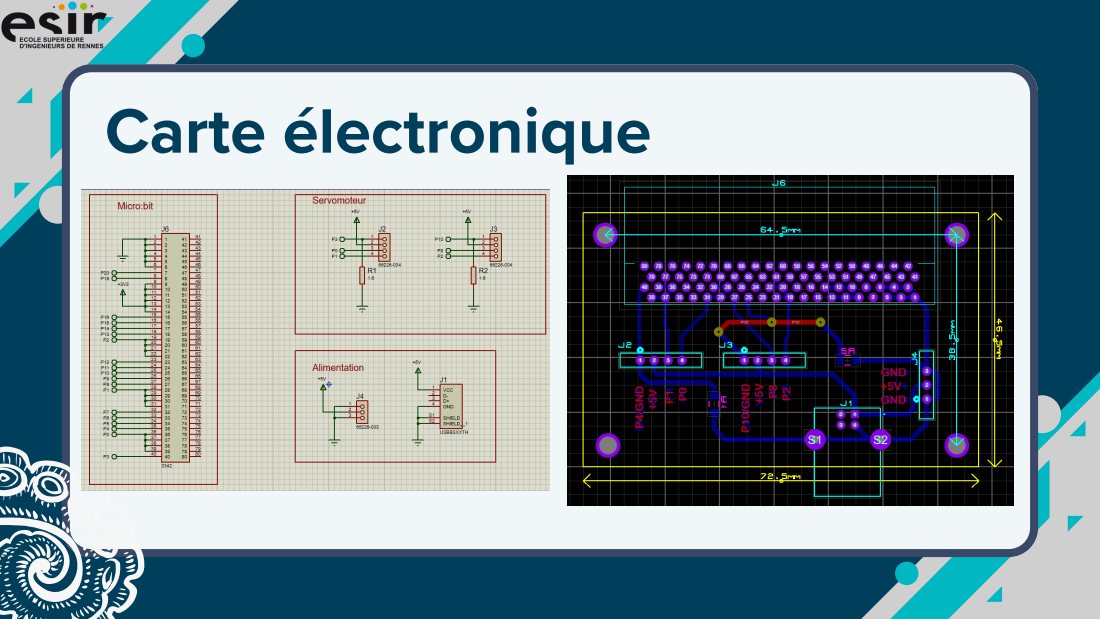
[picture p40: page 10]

## Assemblage

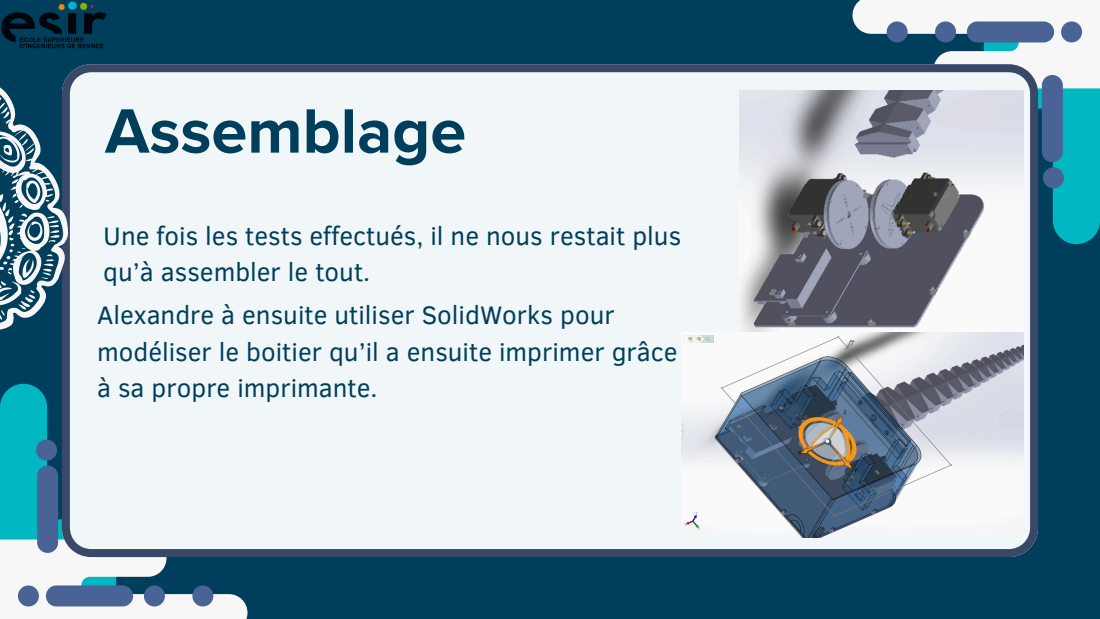
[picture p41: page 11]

Une fois les tests effectués, il ne nous restait plus
qu’à assembler le tout.
Alexandre à ensuite utiliser SolidWorks pour
modéliser le boitier qu’il a ensuite imprimer grâce
à sa propre imprimante.

## Assemblage

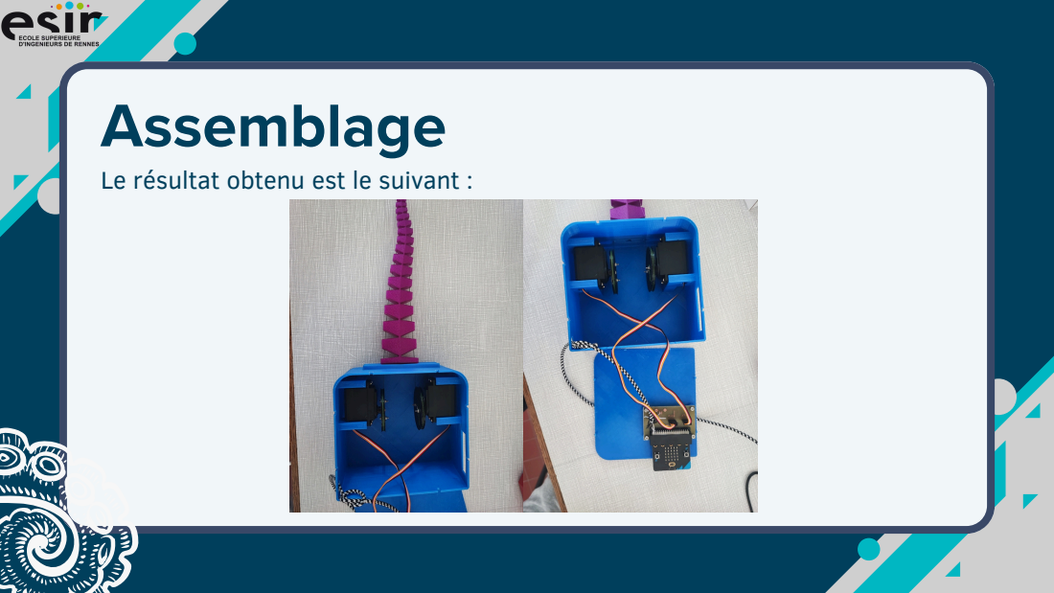
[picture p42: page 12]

Le résultat obtenu est le suivant :

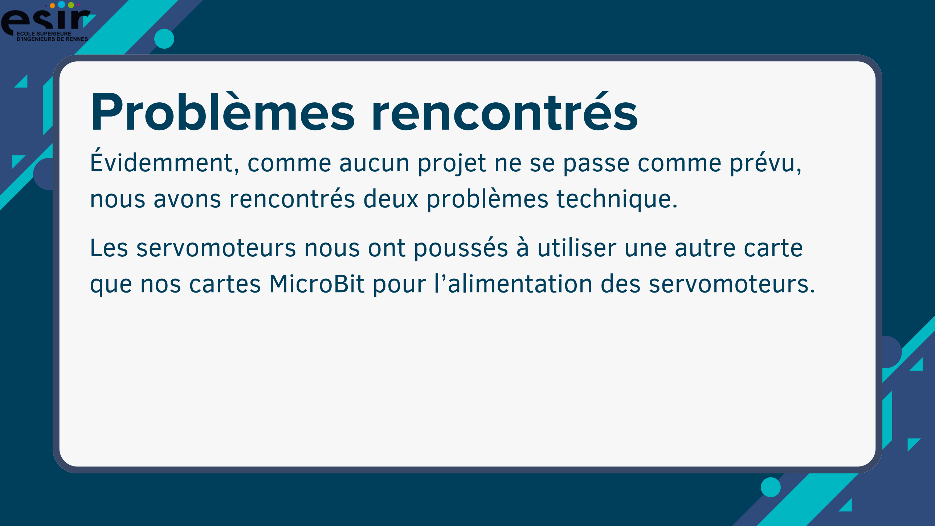
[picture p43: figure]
Problèmes rencontrés

Évidemment, comme aucun projet ne se passe comme prévu, nous avons rencontrés deux problèmes technique.

### Les servomoteurs nous ont poussés à utiliser une autre carte

que nos cartes MicroBit pour l’alimentation des servomoteurs.

Problèmes rencontrés; de poulies (quatres au total !).

### Nous avons ensuite eu du fil à retordre avec les poulies, le fil

sortait de la piste et ne tendait plus le tentacule.

### Pour pallier à ce problème, nous avons créer plusieurs versions

Poulie Version 3 → Poulie Version 4; Problèmes rencontrés

## Code


Github - Spirob (https://github.com/Laasax/programme-spirob)

Démonstration

Voyez par vous mêmes la démonstration de notre SPIROBS

MERCI DE VOTRE ATTENTION

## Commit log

2025-06-08 readme + fichiers conception
    modif du readme
    ajout des fichiers de conception
    -Fichier 3D (solidworks et STL)
    -Carte électronique (gerber et proteus)
    [03 2025 - Liste de course.xlsx, 04 2025 - Liste de course.xlsx, 114020164.psm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]
2025-06-16 ajout de ble reception gyroscope
2025-06-23 maj des fichiers
    [03 2025 - Liste de course.xlsx, 04 2025 - Liste de course.xlsx, FS5109M_Ensemble corps.SLDASM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]
2025-06-23 changement de nom dossier documentation -> datasheets
2025-06-23 ajout de divers documents
    Ajout des documents de restitution dans le cadre de la matiere PROTEC
    *Proposition de projet
    *Rapport
    *Présentation du projet
